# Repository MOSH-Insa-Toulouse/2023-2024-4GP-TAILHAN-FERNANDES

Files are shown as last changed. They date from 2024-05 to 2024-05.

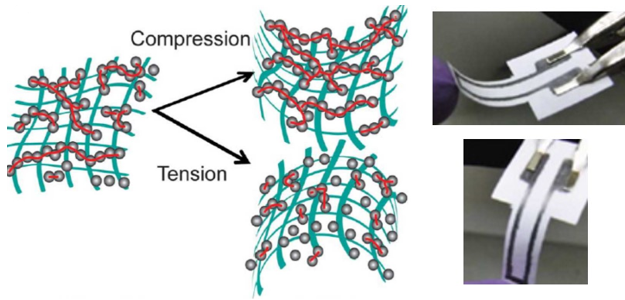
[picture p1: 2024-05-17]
Banc de test/Image_déformation_capteur.png

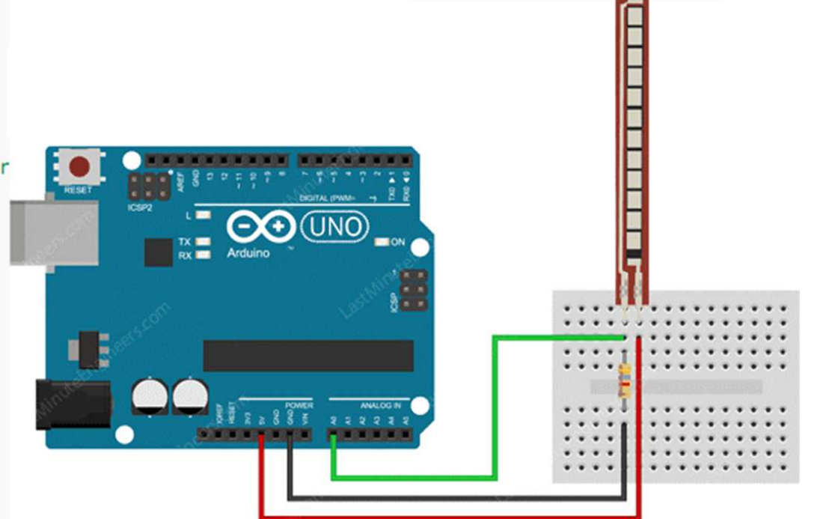
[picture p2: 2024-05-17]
Arduino/Flex sensor/Branchements.PNG

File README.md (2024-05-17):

# 2023-2024-4GP-TAILHAN-FERNANDES
# Projet capteur avec jauge de contrainte de graphène
## Description générale : 
  Nous sommes Amandine Tailhan et David Fernandes, deux élèves de l'INSA Toulouse. Dans le cadre de notre quatrième année, nous avons entrepris un projet sur les capteurs. Notre objectif principal était de déterminer les caractéristiques principales d'une jauge de contrainte low-tech et de les comparer avec sa version conventionnelle, qualifiée de "high-tech". Ce projet vise à répondre à la question suivante : *"Ne pourrait-on pas obtenir parfois les mêmes résultats avec une technologie low-tech qu'avec une technologie high-tech ?"*
<br> <br>
Pour réaliser cette comparaison, nous avons conçu un banc de test à partir de zéro. Sur ce dépôt GitHub, vous trouverez tous les outils et codes que nous avons développés pour répondre à cette question. Enfin, à la fin de ce dépôt, vous découvrirez la réponse à notre problématique.

## Contenu : 
Dans ce github vous retrouverez tout le travail réalisé dans le contexte de ce projet capteur. Vous trouverez un dossier indépendant pour chaque partie de notre projet. <br> <br>
**1. Code Arduino :** Vous trouverez un dossier appelé Arduino dans lequel se trouvent les différents codes arduinos qui pilotent de manière indépendante chacun des composants de notre banc de test et un code appelé "Assemblage_composants" qui pilote l'ensemble de notre banc de test. Dans chaque sous-dossier vous trouverez un schémas des branchements. <br>
**2. Shield dans KiCAD :** Dans le dossier KiCAD  vous trouverez le schéma du montage avec les différents branchements correspondant à notre banc de test : . Vous trouverez également le fichier .pcb que vous pourrez utiliser si vous voulez commander le PCB. La réalisation du PCB permet un meilleur agencement des composants ajoutant ainsi un confort d'utilisation. Cependant, le montage pourra également être réalisé avec des breadboards et des branchements "à la main". <br>
**3. Impression 3D du support:** Notre banc de test utilise un support où l'on vient installer la jauge de contrainte à tester et le servo moteur qui nous servira à appliquer la contrainte sur le capteur. Dans ce dossier vous trouverez le modèle 3D de cette pièce (réalisé sur la version étudiant 10 de PTC Creo) ainsi que le fichier .stl qui vous permettra d'imprimer la pièce avec une imprimante 3D. Cette étape n'est pas obligatoire, vous pouvez très bien réaliser un support pour le capteur et le servo moteur chez vous et ainsi faire votre propre banc de test. <br> 
**4. L'application bluetooth :** À l'aide du logiciel MIT App Inventor nous avons également réalisé une application compatible avec n'importe quel téléphone Android. Cette application permet la communication entre votre smartphone Android et le circuit. Vous pourrez dans cette application visualiser les courbes de contraintes du capteur que vous étudiez. <br>
**5. Datasheet du capteur Low Tech :** Dans le dossier datasheet, vous aurez accès aux informations techniques importantes relatives au capteur. Cela inclut la sensibilité du capteur de graphite pour divers types de crayons tels que F, HB, B, 2B et 4B. Vous y trouverez également des graphiques détaillant la variation relative de résistance en fonction de la déformation selon l'axe z en situation de tension et de compression.
**6. Présentation finale de notre projet :** Vous trouverez parmi les dépôts un document PowerPoint intitulé "Présentation_projet.pptx". Dans ce PowerPoint, nous présentons notre démarche, les différentes étapes du projet, ainsi que des images et une vidéo illustrant le résultat final de notre projet. Cette vidéo pourra vous aider à mieux comprendre et à mieux visualiser l'assemblage de toutes les pièces, c'est pourquoi nous vous invitons à y jeter un œil.

## Pré-requis : 
- Application Arduino, version : >2.1
- Arduino UNO
- Librairies Arduino : Adafruit_SSD1306.h / SPI.h / Servo.h / SoftwareSerial.h
- Smartphone Android (si vous voulez visualiser les courbes de contraintes sur votre smartphone)
- Imprimante 3D (Si vous voulez imprimer le support qu'on propose si vous ne voulez pas faire vous-même le banc de test)
- Commander le PCB (optionnel), sinon 2 breadboards et des fils suffiront 
- Capteur Bluetooth HC05 
- Servo-moteur SM-S2309S
- Encodeur rotatoire KY 040
- Potentiomètre digital MCP 4 1050
- OLED 2864
- Amplificateur opérationnel : LTC1050
- Résistances et condensateurs : voir schémas 

## Guide d'utilisation : 
### Montage :
1. Le premier pas, avant de démarrer, sera de réaliser le montage présenté ci-dessous : 
2. Nous vous recommandons fortement que vous installiez les composants un par un et que vous les testiez individuellement avec les programmes fournis dans /Arduino
schema_montage
1. Une fois les branchements effectués : brancher l'arduino UNO à votre PC 
2. Ouvrez le fichier assemblage.ino qui se trouve dans /Arduino/Assemblage
3. Sélectionnez votre Arduino UNO une fois le programme ouvert 
4. Lancez le code 

### Menu sur l'OLED : 
  Lorsque vous lancez le code sur l'Arduino l'écran OLED s'allume. Sur l'écran OLED vous pourrez accéder à deux menus différents. Le premier menu permet de choisir quelle jauge de contrainte vous voulez mesurer : celle en graphène et la conventionnelle. Le deuxième menu affiche la valeur de la résistance R2 et l'option de recalibration de celle-ci. En effet, en fonction du crayon utilisée pour faire le capteur de graphène la résistance à l'état de repos peut être plus ou moins grande c'est pour celà qu'on a ajouté l'option de recalibration qui permet d'ajuster le gain du montage en modifiant la valeur de la résistance R2. <br> <br>
Pour passer d'un menu à un autre il faut appuyer sur l'encodeur rotatoire. À l'intérieur de chaque menu pour se déplacer parmis les différentes options vous n'avez qu'à faire tourner l'encodeur. Ainsi pour mesurer la résistance de la jauge de contrainte en graphène il faut se placer dans le menu "Résistances" et sélectionner la résistance R graph. D'autre part, pour réaliser la calibration de la résistance R2 il faut se placer dans le menu "Calibration", sélectionner l'option "Recalibration" et appuyer sur l'encodeur 2s.

### Application :

1. Appariez votre smartphone avec votre module Bluetooth HC05. Si un code est demandé, tapez soit 0000 soit 1234.
2. Téléchargez le fichier .exe sur votre smartphone en scannant le QR Code que vous trouverez dans le dossier /Application Android.
3. Une fois l'application installée sur votre Android, accordez les droits nécessaires à votre application afin qu'elle puisse détecter les appareils Bluetooth connectés à votre Android via les paramètres.
4. Ouvrez l'application sur votre smartphone, puis cliquez sur le logo Connect + Bluetooth.
5. Sélectionnez le module HC05.
6. Normalement, la courbe de contrainte de votre capteur s'affiche.
7. Pour afficher la bonne courbe, vous devez introduire manuellement la valeur de R2 (lue sur l'écran OLED, menu : Calibration), puis cliquez sur le bouton "Actualiser R2" de l'application.
8. L'application vous permet également d'arrêter ou de lancer la rotation du servo-moteur avec les boutons : Moteur ON / Moteur OFF.

### Banc de test :

Veuillez trouver ci-dessous une image de notre banc de test : 

<br> <br>
Au centre, vous pouvez observer la pièce principale qui jouera le rôle de support pour notre banc d'essai. À sa droite est positionné le servo-moteur, accompagné du capteur de graphite. À gauche, se trouve l'Arduino UNO et juste au-dessus de celui-ci s'étend notre montage électrique intégré dans le PCB.

Pour réaliser ce banc de test, suivez les étapes suivantes :

#### Support :
1. Vissez l'Arduino UNO sur le support.
2. Réalisez le PCB.
3. Effectuez toutes les soudures nécessaires.
4. Installez le PCB sur l'Arduino. (L'étape de 2 à 4 peut être remplacée par l'utilisation d'un breadboard et de câbles.)
5. Placez le servo-moteur ; les fils du servo-moteur sont à droite du support.
6. Vissez les deux pinces du capteur à gauche du servo-moteur.
7. Sur les "bras" du servo-moteur, vissez un bras suffisamment long pour atteindre le capteur de graphite (4-5cm).
    - Éteignez l'alimentation du servo-moteur.
    - Tournez ses bras dans le sens opposé des aiguilles d'une montre jusqu'au maximum.
    - Maintenant, enlevez le "bras" du servo-moteur et ajustez-le de manière à ce qu'il fasse un angle compris entre -50 et -20 degrés par rapport à l'axe horizontal.
    - Mesurez cet angle et rentrez-le dans le code Arduino dans la variable : angle_min.
    - Ajustez la variable angle_max de manière à ce que le bras du servo-moteur dépasse le capteur.

#### Acquisition de données :
1. Après vérification que tout fonctionne convenablement, fermez le logiciel Arduino (en mémorisant le port sur lequel votre Arduino UNO est connecté).
2. Dans le dossier /Acquisition_donnees, créez un document vide .txt.
3. Ouvrez le code python "enregistrement_donnees.py" que vous trouverez dans : /Acquisition_donnees.
4. Changez le chemin du fichier par le chemin du fichier .txt que vous avez créé.
5. Lancez le code python.
6. Laissez le code tourner jusqu'à la fin.
7. Les données sont normalement stockées dans le fichier .txt (ATTENTION : notez les valeurs de n pour lesquelles le capteur est au repos).

#### Traitement de données :
1. Ouvrez les fichiers .txt avec Excel en choisissant "," comme séparateur de colonne.
2. Effacez toutes les lignes pour lesquelles le capteur est au repos.
3. Ordonnez votre tableau par déformation_z_cm croissante.
4. Enregistrez les données dans le tableau/feuille qui vous paraît pertinent, dans le fichier donnees_courbes.
5. Les courbes sont automatiquement générées dans la feuille : Ensemble.

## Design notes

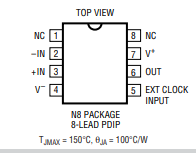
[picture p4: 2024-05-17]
Arduino/Capteur/AOP.PNG

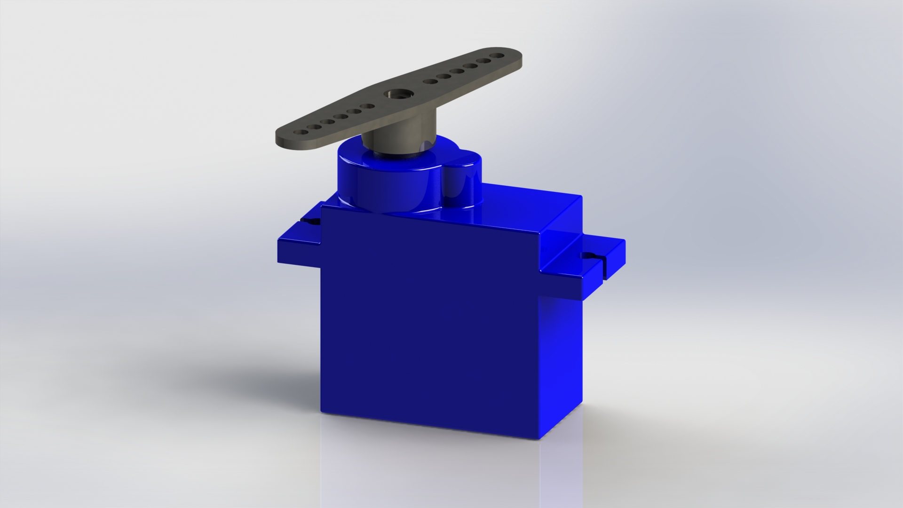
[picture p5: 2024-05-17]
kiCAD/modele/servo-motor-110.snapshot.1/Servo Motor.JPG

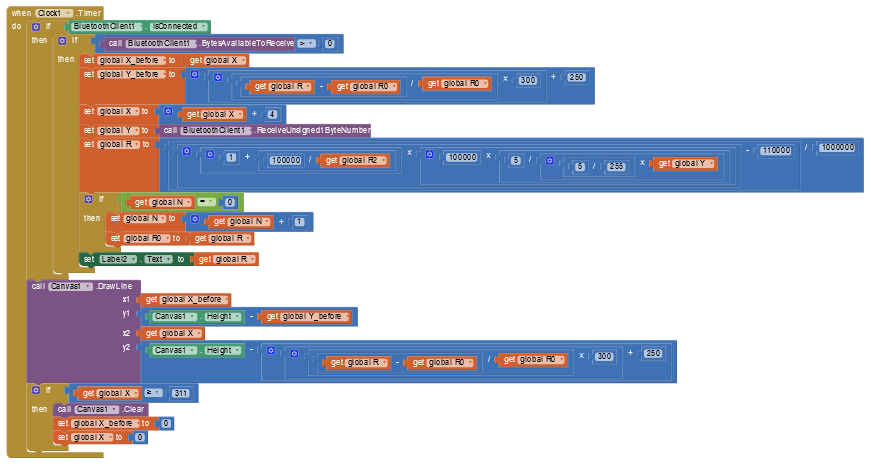
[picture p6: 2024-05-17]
Application Android/Graphique_valeurRmesurée_app.png

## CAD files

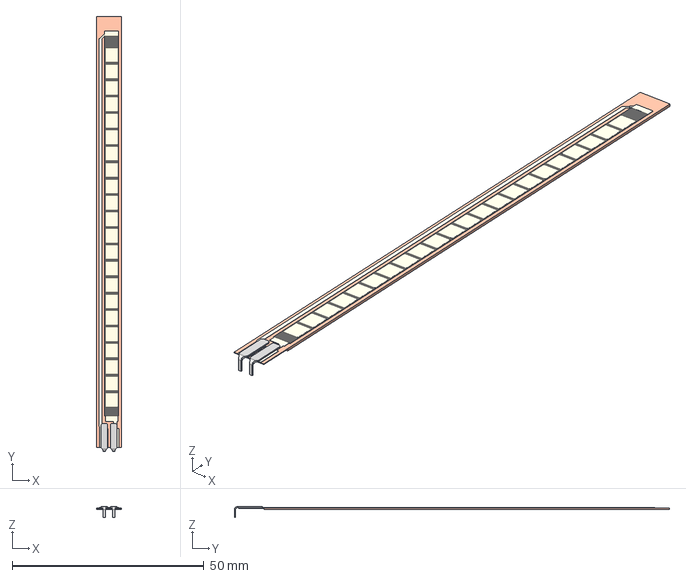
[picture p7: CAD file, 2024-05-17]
kiCAD/modele/FS-L-0095-103-ST - Assembly.stp
6.45 x 113.5 x 2.77 mm
FS-L-0095-103-ST - Base
FS-L-0095-103-ST - Top

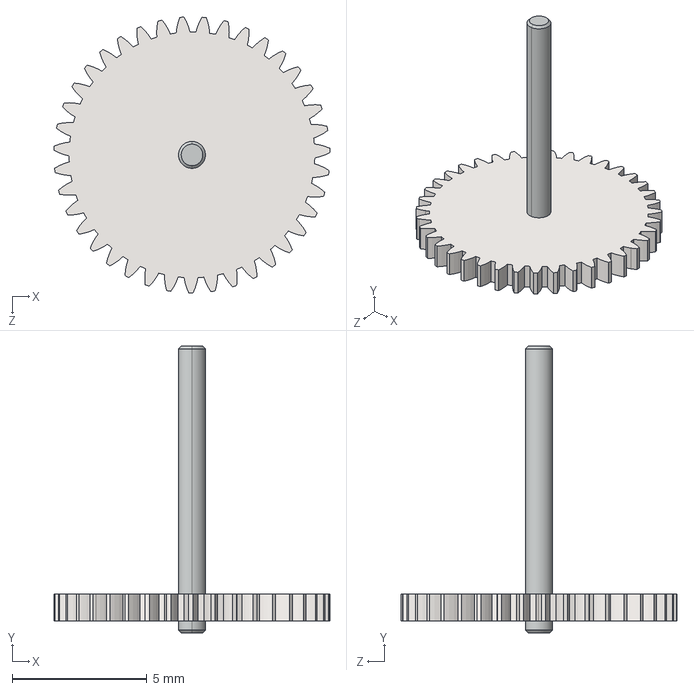
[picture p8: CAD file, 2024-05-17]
kiCAD/modele/servo-motor-110.snapshot.1/Gear_SubAssembly-1-1.STEP
10.2 x 10.7 x 10.2 mm
Shaft^Gear_SubAssembly-1
spur gear_iso_ISO - Spur gear 0.25M 39T 20PA 1FW ---S39A75H50L1.0N

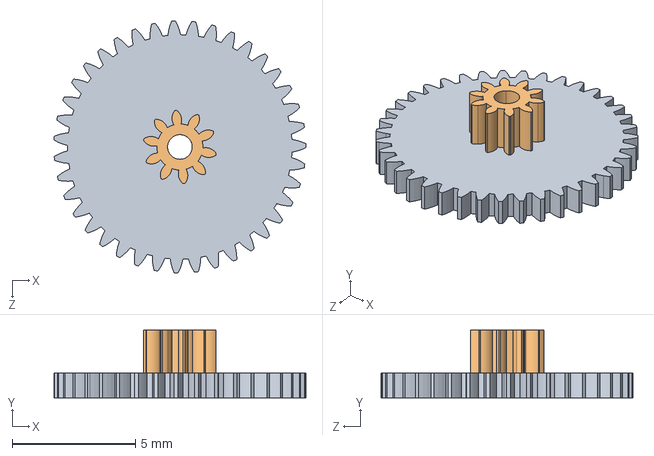
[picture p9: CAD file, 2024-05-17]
kiCAD/modele/servo-motor-110.snapshot.1/Gear_SubAssembly-2.STEP
10.2 x 2.75 x 10.2 mm
spur gear_iso_ISO - Spur gear 0.25M 39T 20PA 1FW ---S39A75H50L1.0N
spur gear_iso_ISO - Spur gear 0.25M 10T 20PA 1.75FW ---S10A75H50L1.0N

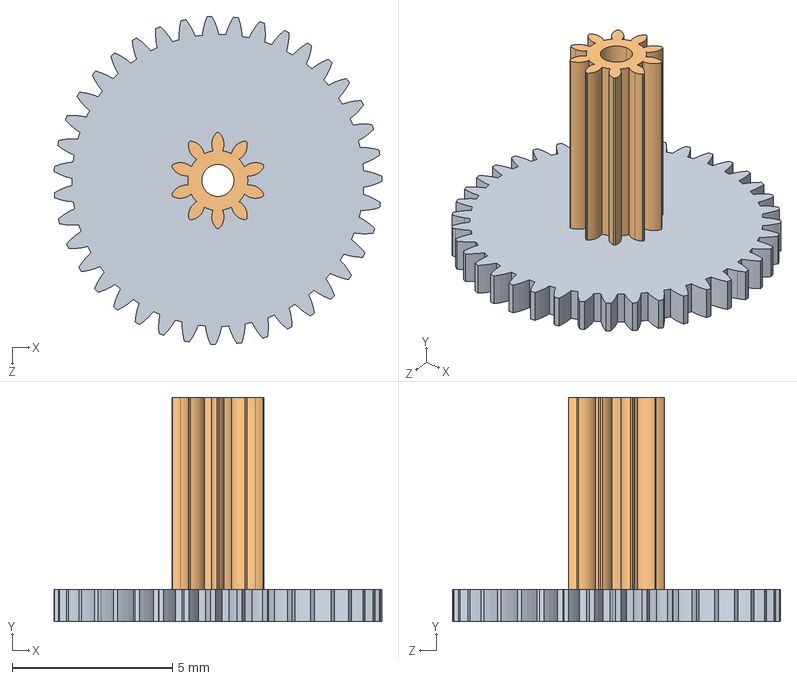
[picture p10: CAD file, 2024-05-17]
kiCAD/modele/servo-motor-110.snapshot.1/Gear_SubAssembly-3.STEP
10.2 x 7.00 x 10.2 mm
spur gear_iso_ISO - Spur gear 0.25M 39T 20PA 1FW ---S39A75H50L1.0N
spur gear_iso_ISO - Spur gear 0.25M 10T 20PA 6FW ---S10A75H50L1.0N

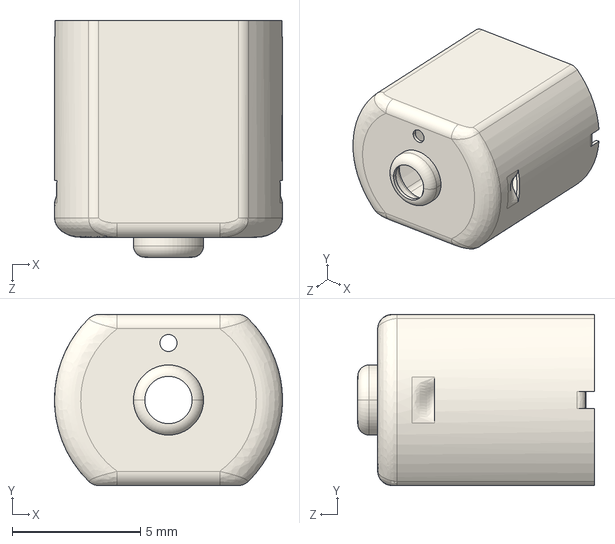
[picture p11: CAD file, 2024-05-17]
kiCAD/modele/servo-motor-110.snapshot.1/Part_1-Housing.STEP
8.90 x 6.68 x 9.23 mm

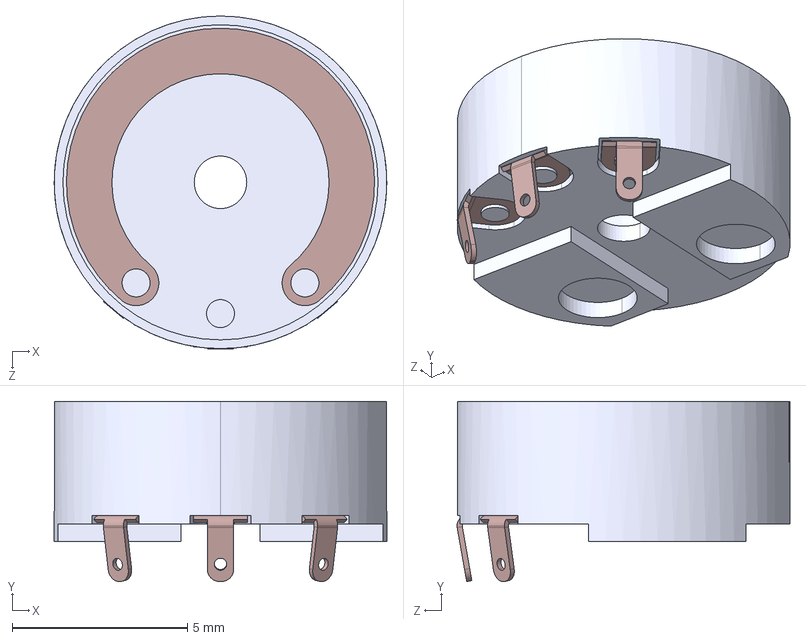
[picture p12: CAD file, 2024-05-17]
kiCAD/modele/servo-motor-110.snapshot.1/Part_1.STEP
9.50 x 5.14 x 9.51 mm

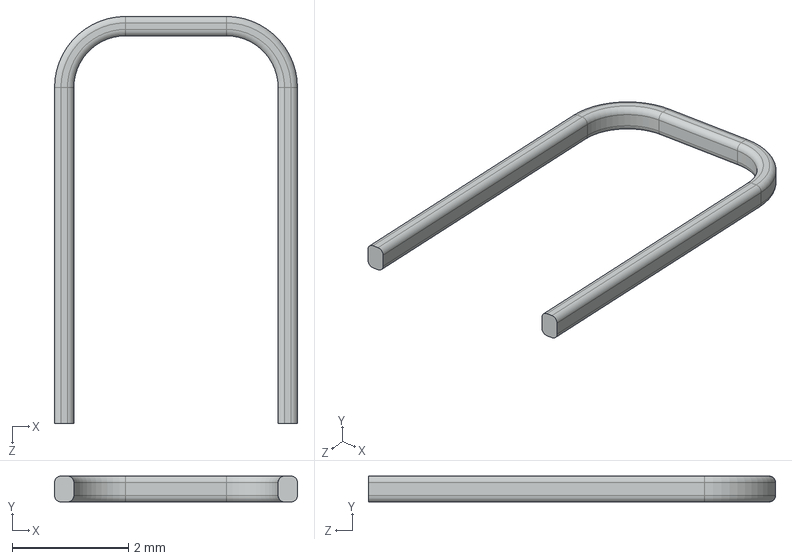
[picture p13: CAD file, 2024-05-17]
kiCAD/modele/servo-motor-110.snapshot.1/Part_5-Spacer.STEP
4.18 x 0.445 x 7.01 mm

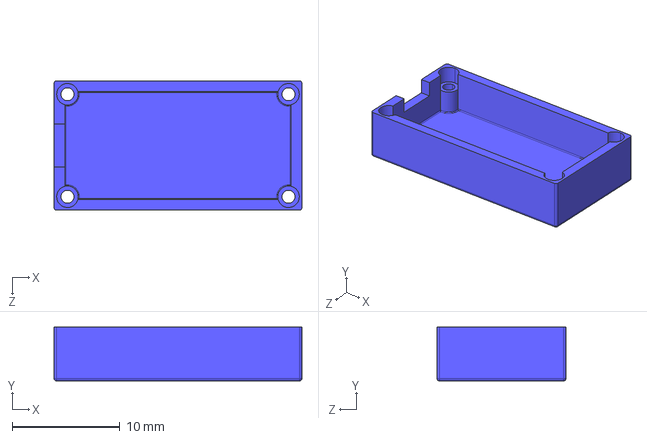
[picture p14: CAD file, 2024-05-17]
kiCAD/modele/servo-motor-110.snapshot.1/Part_3.STEP
23.0 x 5.00 x 12.0 mm

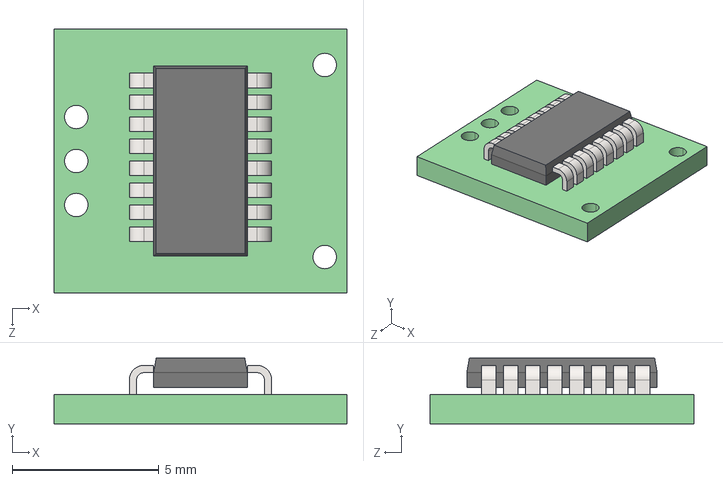
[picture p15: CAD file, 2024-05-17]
kiCAD/modele/servo-motor-110.snapshot.1/Part_8-PCB.STEP
10.0 x 2.25 x 9.00 mm

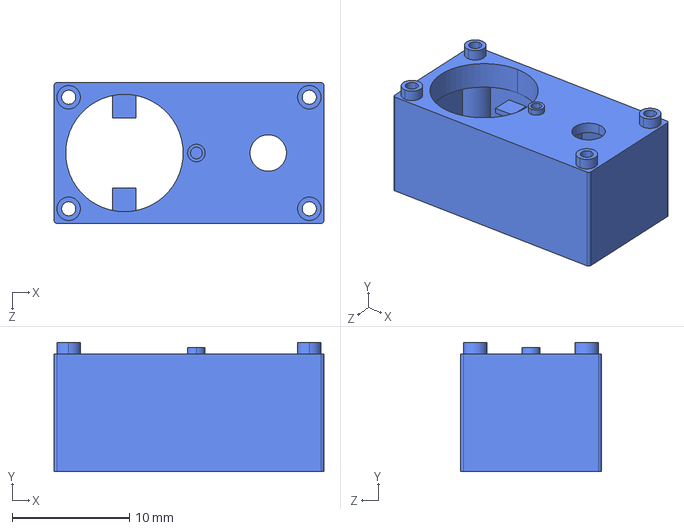
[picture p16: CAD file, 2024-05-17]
kiCAD/modele/servo-motor-110.snapshot.1/Part_4.STEP
23.0 x 11.0 x 12.0 mm

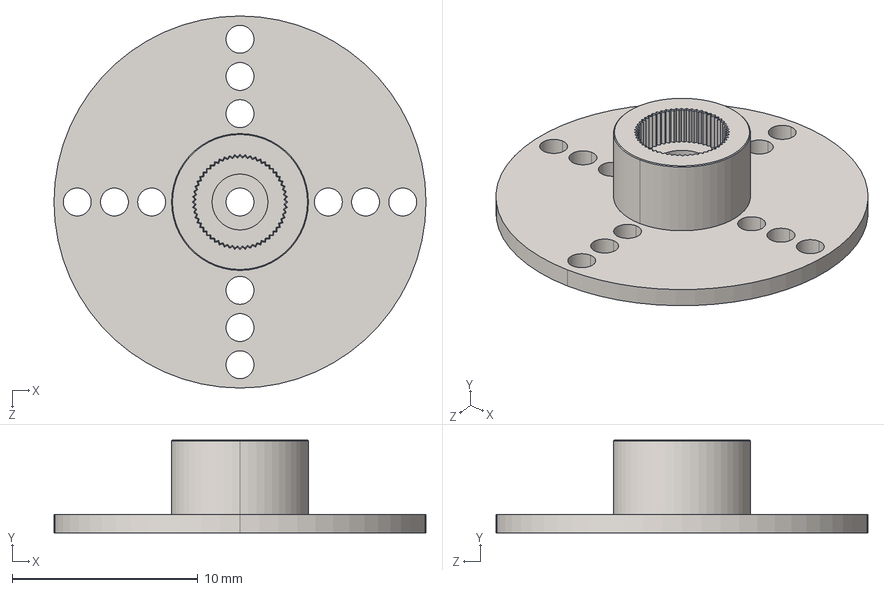
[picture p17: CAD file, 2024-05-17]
kiCAD/modele/servo-motor-110.snapshot.1/Part_7_1.STEP
20.0 x 5.00 x 20.0 mm

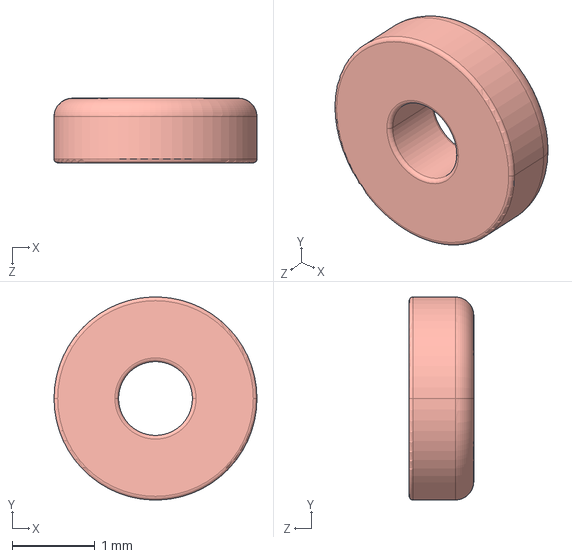
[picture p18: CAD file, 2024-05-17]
kiCAD/modele/servo-motor-110.snapshot.1/Part_7-Brushing 2 Shaft Fixture.STEP
2.45 x 2.45 x 0.779 mm

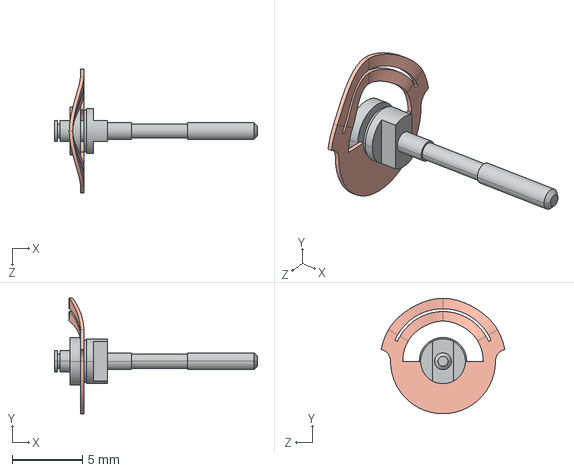
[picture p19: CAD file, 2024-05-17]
kiCAD/modele/servo-motor-110.snapshot.1/Part_2.STEP
14.5 x 8.25 x 8.84 mm

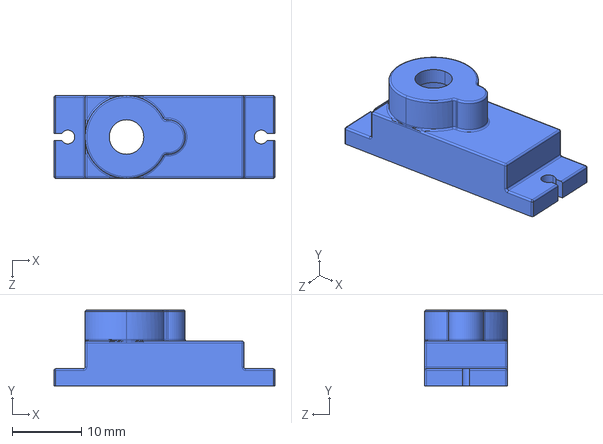
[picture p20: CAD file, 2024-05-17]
kiCAD/modele/servo-motor-110.snapshot.1/Part_5.STEP
32.0 x 11.0 x 12.0 mm

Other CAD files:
kiCAD/modele/servo-motor-110.snapshot.1/Gear_SubAssembly-1.STEP
kiCAD/modele/servo-motor-110.snapshot.1/Part_4-1.STEP
kiCAD/modele/servo-motor-110.snapshot.1/Gear-4.STEP
kiCAD/modele/servo-motor-110.snapshot.1/Part_7.STEP
kiCAD/modele/servo-motor-110.snapshot.1/DC_Motor-Casing.STEP
kiCAD/modele/servo-motor-110.snapshot.1/Part_2-Cover.STEP
kiCAD/modele/servo-motor-110.snapshot.1/Part_3-End Cover.STEP
kiCAD/modele/servo-motor-110.snapshot.1/Part_4-Magnet.STEP
kiCAD/modele/servo-motor-110.snapshot.1/Part_6-Brushing 1.STEP

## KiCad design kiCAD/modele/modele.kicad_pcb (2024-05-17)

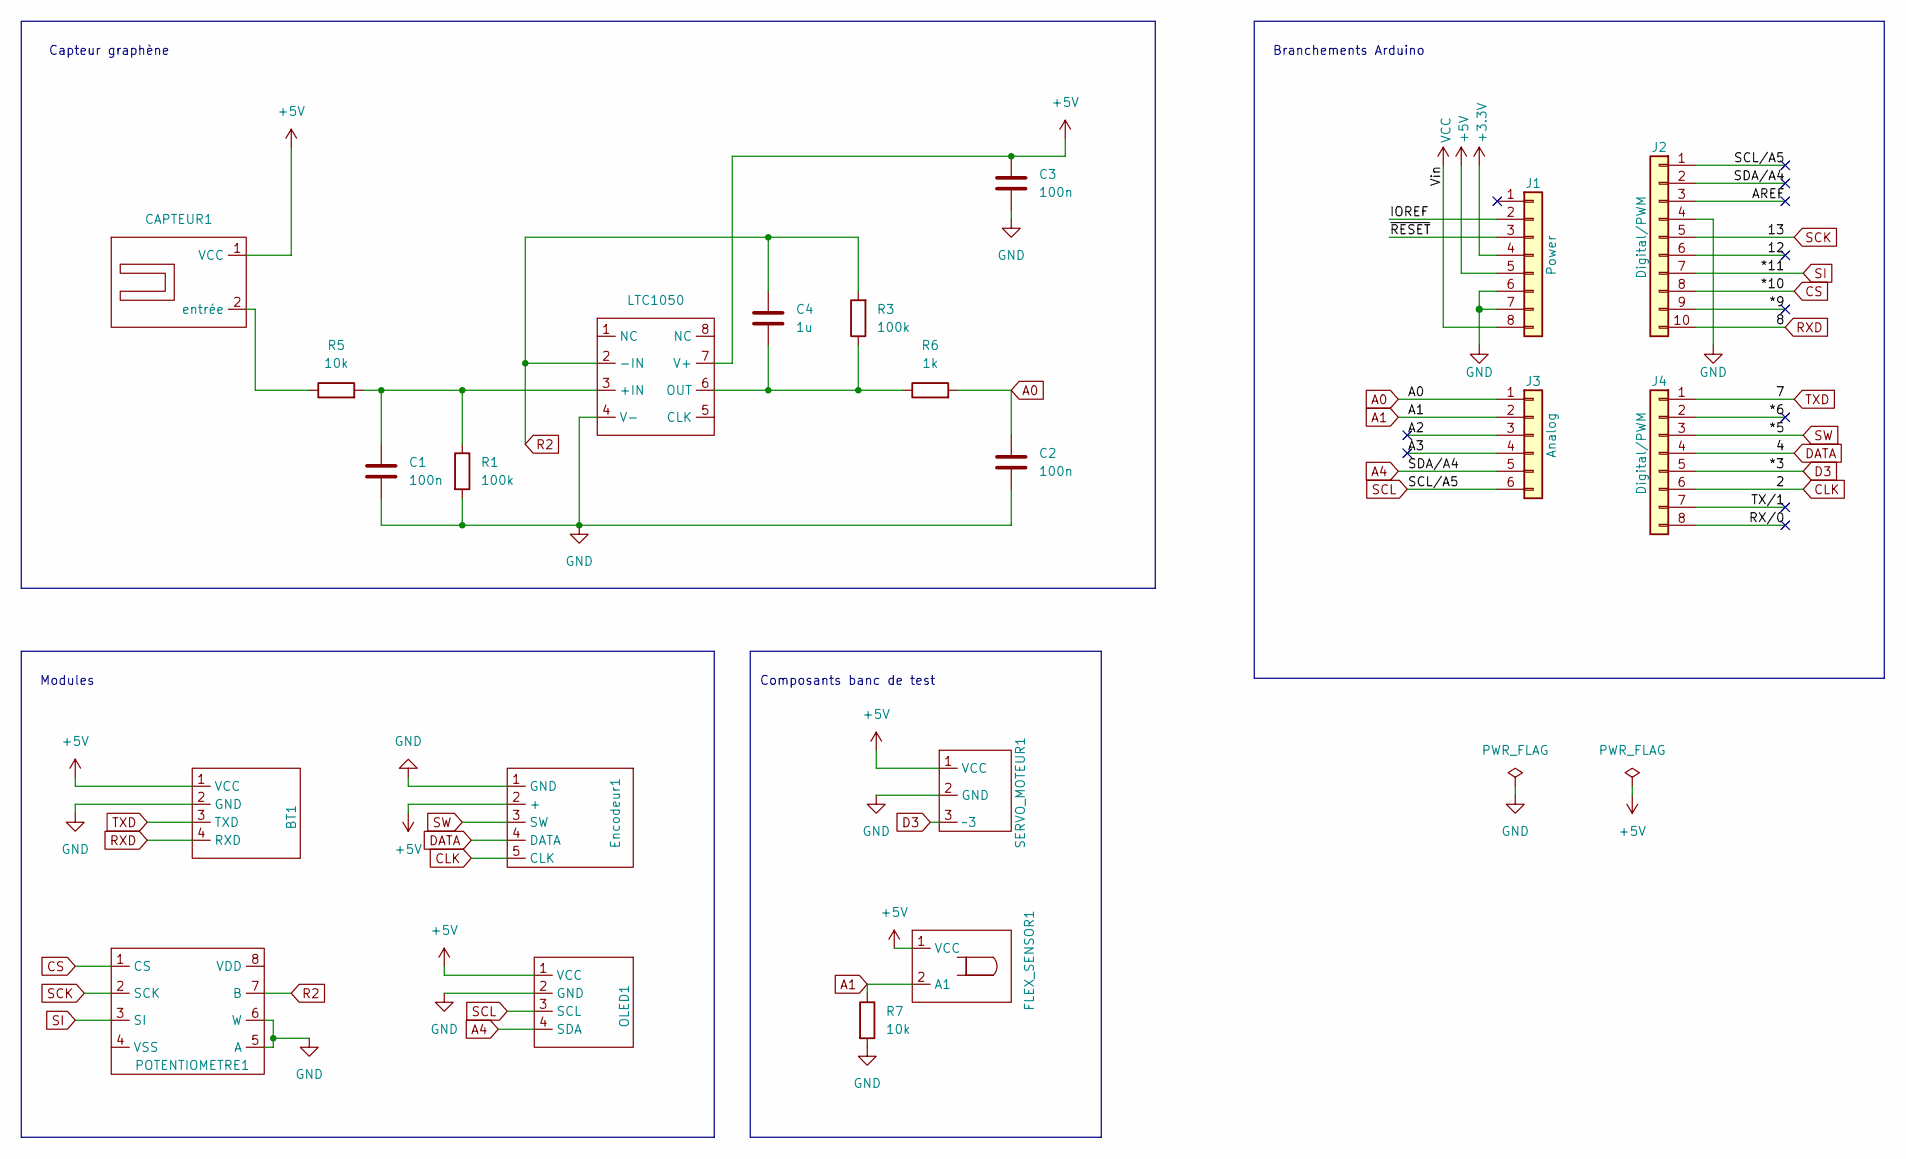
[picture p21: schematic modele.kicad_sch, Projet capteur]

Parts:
BT1: BT
C1, C2, C3: 100n; C_Disc_D4.3mm_W1.9mm_P5.00mm
C4: 1u; C_Rect_L7.0mm_W3.5mm_P5.00mm
CAPTEUR1: capteur
Encodeur1: Encoder KY-040
FLEX_SENSOR1: Flex_Sensor
J1: Power; PinSocket_1x08_P2.54mm_Vertical
J2: Digital/PWM; PinSocket_1x10_P2.54mm_Vertical
J3: Analog; PinSocket_1x06_P2.54mm_Vertical
J4: Digital/PWM; PinSocket_1x08_P2.54mm_Vertical
LTC1050: AOP-LTC1050
OLED1: OLED-2864
POTENTIOMETRE1: MCP41050
R1, R3: 100k; R_Axial_DIN0204_L3.6mm_D1.6mm_P5.08mm_Horizontal
R5, R7: 10k; R_Axial_DIN0204_L3.6mm_D1.6mm_P5.08mm_Horizontal
R6: 1k; R_Axial_DIN0207_L6.3mm_D2.5mm_P7.62mm_Horizontal
SERVO_MOTEUR1: Servo_moteur

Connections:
+3V3: J1.4
+5V: BT1.1 (VCC), C3.1, CAPTEUR1.1 (VCC), Encodeur1.2 (+), FLEX_SENSOR1.1 (VCC), J1.5, LTC1050.7 (V+), OLED1.1 (VCC), SERVO_MOTEUR1.1 (VCC)
/12: J2.6
/*6: J4.2
/*9: J2.9
/A2: J3.3
/A3: J3.4
/AREF: J2.3
/IOREF: J1.2
/RX/0: J4.8
/TX/1: J4.7
/~RESET: J1.3
A0: C2.1, J3.1, R6.2
A1: FLEX_SENSOR1.2 (A1), J3.2, R7.1
A4: J2.2, J3.5, OLED1.4 (SDA)
CLK: Encodeur1.5 (CLK), J4.6
CS: J2.8, POTENTIOMETRE1.1 (CS)
D3: J4.5, SERVO_MOTEUR1.3 (~3)
DATA: Encodeur1.4 (DATA), J4.4
GND: BT1.2 (GND), C1.2, C2.2, C3.2, Encodeur1.1 (GND), J1.6, J1.7, J2.4, LTC1050.4 (V-), OLED1.2 (GND), POTENTIOMETRE1.5 (A), POTENTIOMETRE1.6 (W), R1.2, R7.2, SERVO_MOTEUR1.2 (GND)
unnamed: CAPTEUR1.2 (entrée), R5.1
unnamed: C1.1, LTC1050.3 (+IN), R1.1, R5.2
unnamed: C4.2, LTC1050.6 (OUT), R3.1, R6.1
R2: C4.1, LTC1050.2 (-IN), POTENTIOMETRE1.7 (B), R3.2
RXD: BT1.4 (RXD), J2.10
SCK: J2.5, POTENTIOMETRE1.2 (SCK)
SCL: J2.1, J3.6, OLED1.3 (SCL)
SI: J2.7, POTENTIOMETRE1.3 (SI)
SW: Encodeur1.3 (SW), J4.3
TXD: BT1.3 (TXD), J4.1
VCC: J1.8

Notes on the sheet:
Capteur graphène
Modules
Composants banc de test
Branchements Arduino

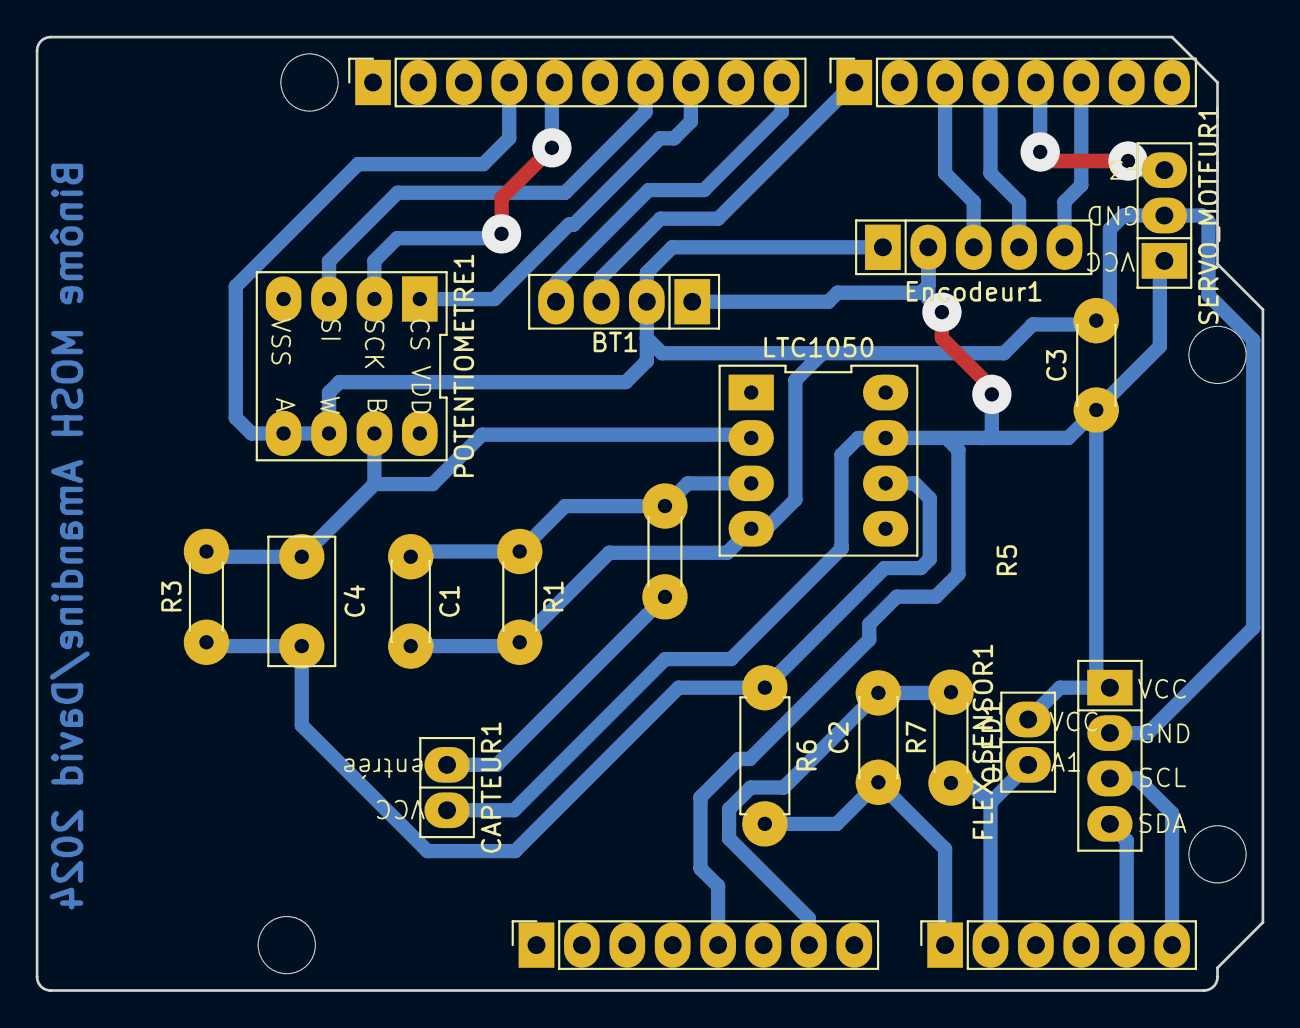
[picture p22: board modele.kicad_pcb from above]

Board: 2 copper layers, 68.6 x 53.3 mm, 25 parts (0 on the bottom side), 19 nets.

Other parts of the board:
MH1, MH2, MH3, MH4: MountingHole_3.2mm

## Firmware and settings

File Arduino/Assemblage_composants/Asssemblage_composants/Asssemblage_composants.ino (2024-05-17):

#include <Adafruit_SSD1306.h> // Bibliothèque pour contrôler l'écran OLED
#include <SPI.h>              // Bibliothèque pour l'utilisation du potentiometre
#include <Servo.h>            // Bibliothèque pour le servo moteur
#include <SoftwareSerial.h>   // Bibliothèque pour connecter le module bluetooth

//Définition des variables OLED
#define nombreDePixelsEnLargeur 128         // Largeur en pixel de l'écran OLED
#define nombreDePixelsEnHauteur 64          // Hauteur en pixel de l'écran OLED
#define brocheResetOLED         -1          // Réinitialisation de l'OLED partagée avec l'Arduino (valeur à -1 pour indiquer qu'aucun numéro de pin spécifique n'est utilisé)
#define adresseI2CecranOLED     0x3C        // Adresse de l'écran OLED sur le bus I2C (généralement égal à 0x3C ou 0x3D)
#define tailleDeCaractere 1                 // Taille des caractères sur l'écran OLED

#define DEBUG
#define CALIBRATION // Si partie non commentée dans la suite du code alors la calibration est automatique sinon la variable potentiometre = 2

//Définition des variables pour l'encodeur rotatif
#define encoder0PinA  2  // Définition de la broche A de sortie CLK de l'encodeur 0. Attention : ne pas utiliser une autre broche pour l'horloge car nous utilisons une interruption
#define encoder0PinB  4  // Définition de la broche B de sortie DT de l'encodeur 0
#define encoderSwitchPin  5 // Définition de la broche associée à l'interrupteur de l'encodeur
volatile unsigned int encoder0Pos = 0;
volatile unsigned int dernier_encodeur = 0;
volatile bool changer = true ; 
volatile int menu = 0; 
boolean buttonWasUp = true;

//Définition des paramètres du Flex sensor
const int flexPin = A1;      // Broche connectée à la sortie du diviseur de tension
//Constantes à modifier en fonction de la conception du projet
const float VCC = 5;      // Tension sur la ligne 5V de l'Arduino
const float R_DIV = 26700.0;  // Résistance utilisée pour créer un diviseur de tension
const float flatResistance = 25000.0; // Résistance lorsque le capteur est plat
const float bendResistance = 100000.0;  // Résistance à 90° de flexion

//Définition de la variable stockant la mesure de la jauge de contrainte en graphène 
int sensorValue ; 

//Définition des variables de choix menu déroulant
volatile int R_mesuree; // Variable volatile contenant la mesure de R, prenant la valeur 1 (pour la résistance du graphène) ou 0 (pour la résistance du Flex Sensor)
volatile float calibre ; 

//Définition des variables du potentiomètre
#define MCP_NOP 0b00000000
#define MCP_WRITE 0b00010001
#define MCP_SHTDWN 0b00100001
const int ssMCPin = 10; // Définition de la sélection d'esclave pour le potentiomètre digital
#define WAIT_DELAY 200
int potentiometre = 30; // Valeur comprise entre 1 et 256
volatile float R2 ;
float V_ADC ;
float RJC ; 

//Définition des variables du servo moteur
Servo myservo;  // Création d'un objet servo pour contrôler un servo
                // Un maximum de huit objets servo peut être créé
int pin_servo_moteur = 3 ; // Attention, broche qui doit contenir un "~" sur l'Arduino
int Servo_App_Value = 1; 
float R = 6.2 ; // Longueur du bras du servo-moteur (en cm)
int angle_0 = 0 ; // Angle du servo-moteur à la position de repos (en degrés)
int angle_max = 75 ; // Angle du servo-moteur à la position max (en degrés)
const float pi = 3.14159 ;
int pos = angle_0;    // Variable pour enregistrer la position du servo-moteur
bool isRunning = true;

//Définition des variables pour le module Bluetooth
//byte Rbyte_BT ; // Valeur de la résistance à envoyer au module Bluetooth
#define rxPin 7 // Définition de la broche 7 comme broche de réception pour la communication série avec le Bluetooth HC-05. Attention, la broche TX du HC-05 doit être connectée à cette broche
#define txPin 8 // Définition de a broche 8 comme branche de transmission pour la communication série avec le Bluetooth HC-05. Attention, la broche RX du HC-05 doit être connectée à cette broche
SoftwareSerial bluetooth_serial (rxPin ,txPin); // Initialisation avec les pin rx et tx d'une communication série logicielle pour la communication avec le module Bluetooth

//Définition d'un entier pour l'enregistrement des données au format csv
int n = 0 ; 

Adafruit_SSD1306 ecranOLED(nombreDePixelsEnLargeur, nombreDePixelsEnHauteur, &Wire, brocheResetOLED); // Initialisation OLED

//Fonction potentiomètre
void SPIWrite(uint8_t cmd, uint8_t data, uint8_t ssPin) // Ecriture SPI de la commande et des données vers le circuit MCP connecté à la broche ssPin
{
  SPI.beginTransaction(SPISettings(14000000, MSBFIRST, SPI_MODE0)); // Voir https://www.arduino.cc/en/Reference/SPISettings
  
  digitalWrite(ssPin, LOW); // Met la broche ss à l'état bas 
  
  SPI.transfer(cmd);        // Envoie le code de la commande
  SPI.transfer(data);       // Envoie la valeur associée
  
  digitalWrite(ssPin, HIGH); // Remet la broche ss à l'état haut pour déselectionner le circuit
  SPI.endTransaction();      // Fin de la transaction SPI
}

//Calibration de la résistance R2 avec le potentiomètre
void Calibration() {
    //Configuration du potentiomètre
    pinMode (ssMCPin, OUTPUT); // Définition du mode de la broche ssMCPin comme sortie
    digitalWrite(ssMCPin, HIGH); // Désactivation de la puce SPI en mettant la broche ssMCPin à l'état haut
    SPI.begin(); // Initialisation de la communication SPI

    //Calibration de valeur de resistance mesurée pour que la valeur mesurée de A0 soit autour de 2.5V
    sensorValue = analogRead(A0);
    SPIWrite(MCP_WRITE, potentiometre, ssMCPin); 
    delay (WAIT_DELAY);

#ifdef CALIBRATION
  while ((sensorValue<400 || sensorValue>700) && (potentiometre > 1 && potentiometre<256) ) {
    if (sensorValue<400 && potentiometre > 0) {potentiometre = potentiometre - 1 ;}
    else {if (potentiometre<256 && sensorValue>700) {potentiometre = potentiometre + 1 ;}}
    Serial.println("CALIBRATION");
    Serial.println(potentiometre);
    SPIWrite(MCP_WRITE, potentiometre, ssMCPin);
    sensorValue = analogRead(A0);
    delay (WAIT_DELAY);
  }
#endif  

#ifndef CALIBRATION
  potentiometre = 255 ; 
  SPIWrite(MCP_WRITE, potentiometre, ssMCPin); 
#endif  
}

//La routine de configuration s'exécute une seule fois lorsque vous appuyez sur le bouton de réinitialisation
void setup() {
  //Configuration OLED
  ecranOLED.begin(SSD1306_SWITCHCAPVCC, adresseI2CecranOLED);  // Initialisation de l'écran
  ecranOLED.clearDisplay();                                    // Efface de l'intégralité du buffer de l'écran OLED
  ecranOLED.setTextSize(tailleDeCaractere);                    // Taille des caractères (1:1, puis 2:1, puis 3:1)
  ecranOLED.setCursor(0, 0);                                   // Déplacement du curseur en position (0,0), c'est à dire dans l'angle supérieur gauche de l'écran OLED
  ecranOLED.setTextColor(SSD1306_BLACK, SSD1306_WHITE);        // Couleur du texte, couleur du fond

  //Configuration encodeur rotatif
  pinMode(encoder0PinA, INPUT);           // Configure la broche A de l'encodeur en entrée
  digitalWrite(encoder0PinA, HIGH);       // Active la résistance pull-up pour la broche A de l'encodeur
  pinMode(encoder0PinB, INPUT);           // Configure la broche B de l'encodeur en entrée
  digitalWrite(encoder0PinB, HIGH);       // Active la résistance pull-up pour la broche B de l'encodeur 
  attachInterrupt(0, doEncoder, RISING);  // Attache l'interruption à la broche 0 pour l'encodeur
  pinMode (encoderSwitchPin, INPUT_PULLUP);

  //Initialisation de la communication série à 9600 bits par seconde
  Serial.begin(9600);
  Serial.println(F("n,Pos,Deformation_z_cm,Sensorvalue,RJC")) ; 

  //Configuration du module Bluetooth 
  pinMode(rxPin,INPUT);
  pinMode(txPin,OUTPUT);
  bluetooth_serial.begin(9600);

  //Configuration du potentiomètre
  pinMode (ssMCPin, OUTPUT); // Définition du mode de la broche ssMCPin comme sortie
  digitalWrite(ssMCPin, HIGH); // Désactivation de la puce SPI en mettant la broche ssMCPin à l'état haut
  SPI.begin();  // Initialisation de la communication SPI

  //Calibration de la valeur de la résistance mesurée pour que la valeur mesurée de A0 soit autour de 2.5V
  sensorValue = analogRead(A0);
  
  //Calibration de la resistance R2 avec le potentiomètre
  Calibration();
  R2 = potentiometre * 31500/255; // Supposition que la relation est lineaire, valeur de R2

  //Initialisation du servo moteur
  myservo.attach(pin_servo_moteur);

  //Configuration du Flex Sensor 
  pinMode(flexPin, INPUT); // Définition de la broche flexPin (A1) en mode lecture (pour le Flex Sensor)
}



//Boucle infinie
void loop() {
  n++ ; 
  int t1 = millis();

  //Gestion du servo-moteur
  if (bluetooth_serial.available() > 0) {
    String command = bluetooth_serial.readStringUntil('\n');
    if (command.equals("start")) {
      isRunning = true;
    } else if (command.equals("stop")) {
      isRunning = false;
    }
  }
  if (isRunning) {
    if (pos == angle_max) {pos = -pos ;}
    if (pos == -angle_0) {pos = -pos ;}
    myservo.write(abs(pos));              // Indique au servo-moteur de se rendre à la position stockée dans la variable 'pos'
    pos = pos + 1 ;
    delay(0) ; 
  }


  //Lecture de la valeur d'entrée sur la broche analogique 0 (capteur de graphène)
  sensorValue = analogRead(A0);

  //Affichage de la valeur de la résistance mesurée
  V_ADC = 5.0/1023.0 * sensorValue ; // Valeur mesurée par A0 en volt
  RJC = abs((1 + 100000/R2)*100000*5/V_ADC-110000)/1000 ; // Valeur de la résistance de graphène nommée RJC en kohms
  Serial.print(n);
  Serial.print(F(","));
  Serial.print(abs(pos));
  Serial.print(F(","));
  Serial.print(R*(sin((24-pos)*pi/180)));
  Serial.print(F(","));
  Serial.println(sensorValue);
  Serial.print(F(","));
  Serial.println(RJC); // Affichage de la valeur de RJC en kohms
  
  //Gestion du Flex Sensor
  int ADCflex = analogRead(flexPin);

  float Vflex = ADCflex * VCC / 1023.0;
  float Rflex = R_DIV * (VCC / Vflex - 1.0);
  float angle = map(Rflex, flatResistance, bendResistance, 0, 90.0);

  //Gestion du menu deroulant (encodeur rotatif)
  if (digitalRead(encoderSwitchPin) == LOW && !(menu==1 && changer==0)) {
    if (menu==0) {menu = 1 ;} 
    else {menu=0;}
    delay(50) ; 
  }

  //Gestion de l'écran OLED
  ecranOLED.clearDisplay();                                   // Efface tout le contenu du tampon de l'écran OLED
  ecranOLED.setTextSize(tailleDeCaractere);                   // Taille des caractères 

  if (encoder0Pos != dernier_encodeur) {
    if (changer == 1) {changer = false ;}
    else {changer = true;}
  }
  
  R2 = potentiometre * 31500/255; // En supposant que relation lineaire, valeur de R2

  //Gestion du menu de l'encodeur rotatif (choix résistance et calibre)
  if(menu == 0) {
    if (changer) { //Menu du choix de résistances
      R_mesuree = 1 ; // Mesure de la résistance de graphène
      ecranOLED.setCursor(0, 0); // Déplacement du curseur en position (0,0), c'est à dire dans l'angle supérieur gauche de l'écran
      ecranOLED.setTextColor(SSD1306_WHITE, SSD1306_BLACK);    // Couleur du texte, couleur du fond
      ecranOLED.println("Resistances(Mohms):");  
      ecranOLED.setCursor(0, tailleDeCaractere * 10);          // Gestion de la taille de l'affichage de l'écriture
      ecranOLED.setTextColor(SSD1306_BLACK, SSD1306_WHITE);    // Couleur du texte, couleur du fond
      ecranOLED.println("R graph:");                        
      ecranOLED.setCursor(tailleDeCaractere * 10 * 5, tailleDeCaractere * 10);
      ecranOLED.println(int(RJC/1000));
      ecranOLED.setCursor(0, tailleDeCaractere * 10 * 2);
      ecranOLED.setTextColor(SSD1306_WHITE, SSD1306_BLACK);    // Couleur du texte, couleur du fond
      ecranOLED.println("R flex:");
      ecranOLED.setCursor(tailleDeCaractere * 10 * 5, tailleDeCaractere * 10 *2);
      ecranOLED.print((Rflex/1000000.0) , 3);
    }
    else { 
      R_mesuree = 0 ; // Mesure de la résistance du Flex Sensor
      ecranOLED.setCursor(0, 0);
      ecranOLED.setTextColor(SSD1306_WHITE, SSD1306_BLACK);     
      ecranOLED.println("Resistances(Mohms):");  
      ecranOLED.setCursor(0, tailleDeCaractere * 10);
      ecranOLED.setTextColor(SSD1306_WHITE, SSD1306_BLACK);     
      ecranOLED.println("R graph:");                              
      ecranOLED.setCursor(tailleDeCaractere * 10 * 5, tailleDeCaractere * 10);
      ecranOLED.println(int(RJC/1000));                         // Affichage de valeur de résistance du Flex Sensor
      ecranOLED.setCursor(0, tailleDeCaractere * 10 * 2);
      ecranOLED.setTextColor(SSD1306_BLACK, SSD1306_WHITE);       
      ecranOLED.println("R flex:");
      ecranOLED.setCursor(tailleDeCaractere * 10 * 5, tailleDeCaractere * 10 *2);
      ecranOLED.print((Rflex/1000000.0) , 3);
    }
  }
  else {
    if (changer) { //Menu Calibre
      ecranOLED.setCursor(0, 0); // Déplacement du curseur en position (0,0), c'est à dire dans l'angle supérieur gauche de l'écran OLED
      ecranOLED.setTextColor(SSD1306_WHITE, SSD1306_BLACK);   
      ecranOLED.println("Calibre R2:");  
      ecranOLED.setCursor(0, tailleDeCaractere * 10);  
      ecranOLED.setTextColor(SSD1306_BLACK, SSD1306_WHITE);    
      ecranOLED.println("R2 (kohms):");                        
      ecranOLED.setCursor(tailleDeCaractere * 10 * 6, tailleDeCaractere * 10);
      ecranOLED.println(abs(int(potentiometre * 31.500/255)));
      ecranOLED.setCursor(0, tailleDeCaractere * 10 * 2);
      ecranOLED.setTextColor(SSD1306_WHITE, SSD1306_BLACK);         
      ecranOLED.println("Recalibration");
    }
    else {
      ecranOLED.setCursor(0, 0); 
      ecranOLED.setTextColor(SSD1306_WHITE, SSD1306_BLACK);    
      ecranOLED.println("Calibre R2:");  
      ecranOLED.setCursor(0, tailleDeCaractere * 10);  
      ecranOLED.setTextColor(SSD1306_WHITE, SSD1306_BLACK);    
      ecranOLED.println("R2 (kohms):");                        
      ecranOLED.setCursor(tailleDeCaractere * 10 * 6, tailleDeCaractere * 10);
      ecranOLED.println(abs(int(potentiometre * 31.500/255)));
      ecranOLED.setCursor(0, tailleDeCaractere * 10 * 2);
      ecranOLED.setTextColor(SSD1306_BLACK, SSD1306_WHITE);       
      ecranOLED.println("Recalibration");

      //Programme de recalibration : permet à l'utilisateur de changer la valeur du potentiomètre R2
      if (digitalRead(encoderSwitchPin) == LOW) {
        potentiometre = 30 ; 
        Calibration();
      }
    }
  }
  dernier_encodeur = encoder0Pos ; 
  ecranOLED.display();

  //Module Bluetooth
  //Détermination de la valeur envoyée au module Bluetooth
  if (R_mesuree==1) { //Capteur graphène
    byte Rbyte_BT = map(analogRead(A0),0,1024,0,255) ; // Transformation d'une valeur codée sur 10 bits en une valeur codée sur 8 bits
    //Serial.println(Rbyte_BT);
    bluetooth_serial.write(Rbyte_BT) ; // Envoie d'un octet au module Bluetooth via la communication série
    delay(50);
    int t2 = millis() ; 
    //Serial.println (t2 - t1);
  }
  else { //Flex Sensor
    byte Rbyte_BT = map(ADCflex , 0,1024,0,255) ; 
    bluetooth_serial.write(Rbyte_BT) ; 
    delay(40);
  }

  //delay(100);  // Délai de 100ms entre les lectures pour assurer la stabilité
}

//Encodeur rotatif
//Mise à jour de la position de l'encodeur en fonction de l'état de la broche associée à la sortie B
void doEncoder() {
  if (digitalRead(encoder0PinB)==HIGH) {
    encoder0Pos++;
  } else {
    encoder0Pos--;
  }
}

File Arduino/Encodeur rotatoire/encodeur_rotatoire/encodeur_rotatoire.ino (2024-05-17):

/* Read a rotary encoder with interrupts
   Encoder hooked up with common to GROUND,    encoder0PinA to pin 2, encoder0PinB to pin 4
   it doesn't matter which encoder pin you use for A or B  
*/ 

#define encoder0PinA  2  //CLK Output A Do not use other pin for clock as we are using interrupt
#define encoder0PinB  4  //DT Output B
#define Switch 5 // Switch connection if available

volatile unsigned int encoder0Pos = 0;

void setup() { 
  pinMode(encoder0PinA, INPUT); 
  digitalWrite(encoder0PinA, HIGH);       // turn on pullup resistor

  pinMode(encoder0PinB, INPUT); 
  digitalWrite(encoder0PinB, HIGH);       // turn on pullup resistor

  attachInterrupt(0, doEncoder, RISING); // encoder pin on interrupt 0 - pin2

  Serial.begin (9600);
  Serial.println("start");                // a personal quirk
} 

void loop(){
  //do some stuff here - the joy of interrupts is that they take care of themselves
  Serial.print("Position:");
  Serial.println (encoder0Pos, DEC);  //Angle = (360 / Encoder_Resolution) * encoder0Pos
}

void doEncoder() {
  if (digitalRead(encoder0PinB)==HIGH) {
    encoder0Pos++;
  } else {
    encoder0Pos--;
  }
}

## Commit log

2024-05-17 Add files via upload
    Addition de la data excel des courbe déformation
    [A_courbes_relative_resistance.xlsx, A_donnees_courbe_flexsensor.xlsx, A_donnees_courbes.xlsx]
2024-05-17 Add files via upload
    Bon dossier d'acquisition des donnees
    [A_courbes_relative_resistance.xlsx, A_donnees_courbe_flexsensor.xlsx, A_donnees_courbes.xlsx]
2024-05-17 Add files via upload
    Addition des dossiers
2024-05-17 Supprimer le dossier Ensembles_donnees
    [A_courbes_relative_resistance.xlsx, A_donnees_courbe_flexsensor.xlsx, A_donnees_courbes.xlsx]
2024-05-17 Add files via upload
    Addition de dossier KiCAD
    [DC_Motor-Casing.STEP, FS-L-0095-103-ST - Assembly.stp, Gear-4.STEP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]
2024-05-17 Addition de dossier avec programmes arduino
2024-05-17 Addition images pcb
